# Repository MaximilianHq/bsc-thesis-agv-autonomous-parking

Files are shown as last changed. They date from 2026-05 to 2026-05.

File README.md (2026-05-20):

# BSc Thesis – AGV Autonomous Parking

Bachelor thesis project focused on developing an autonomous parking system prototype 
using an **Automated Guided Vehicle (AGV)** and a **Supervisory System (ÖS)**.

Developed in collaboration with **Autopark AB**.

<p align="center">
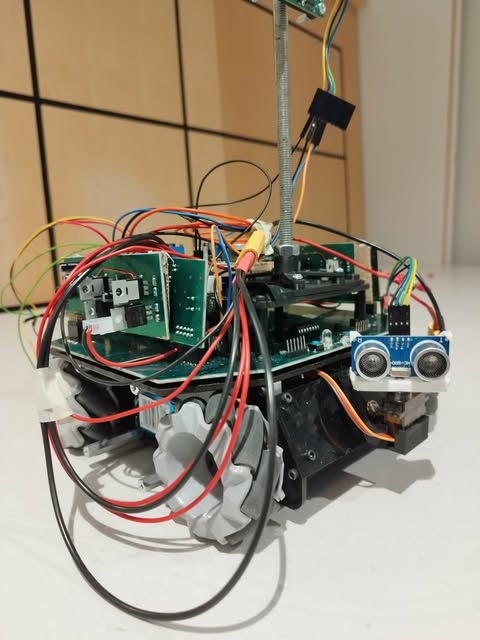
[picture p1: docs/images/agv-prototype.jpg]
  
</p>

<p align="center">
  <i>AGV prototype used for autonomous parking demonstrations</i>
</p>

---

## Overview

This project explores a cost-effective autonomous parking solution for **non-self-parking vehicles**.

The concept is based on an **AGV capable of towing vehicles** by lifting the front axle and transporting 
them to available parking spaces inside a parking garage. The system combines autonomous navigation
with a supervisory control system that handles route planning, parking allocation, and real-time monitoring.

The project demonstrates an integrated interaction between:

- **AGV (Automated Guided Vehicle)** — responsible for physical navigation and vehicle transportation
- **Supervisory System (ÖS)** — responsible for logistics, planning, and visualization

Communication between the AGV and the supervisory system is handled wirelessly via **Bluetooth**.

---

## Project Objective

The objective is to develop a fully functional prototype where the AGV:

1. Retrieves a vehicle from the parking entrance  
2. Selects the optimal parking location  
3. Navigates autonomously to the parking spot  
4. Parks the vehicle  
5. Returns to the entrance  

The complete cycle should be repeatable **at least five times within ten minutes**, 
coordinated through instructions from the supervisory system.

---

## System Architecture

### AGV Subsystem

The AGV is responsible for:

- Autonomous navigation
- Vehicle transport
- Obstacle avoidance
- Parking execution
- Wireless communication with the supervisory system

The AGV software is developed using **PlatformIO** and runs on an embedded microcontroller architecture.

<p align="center">
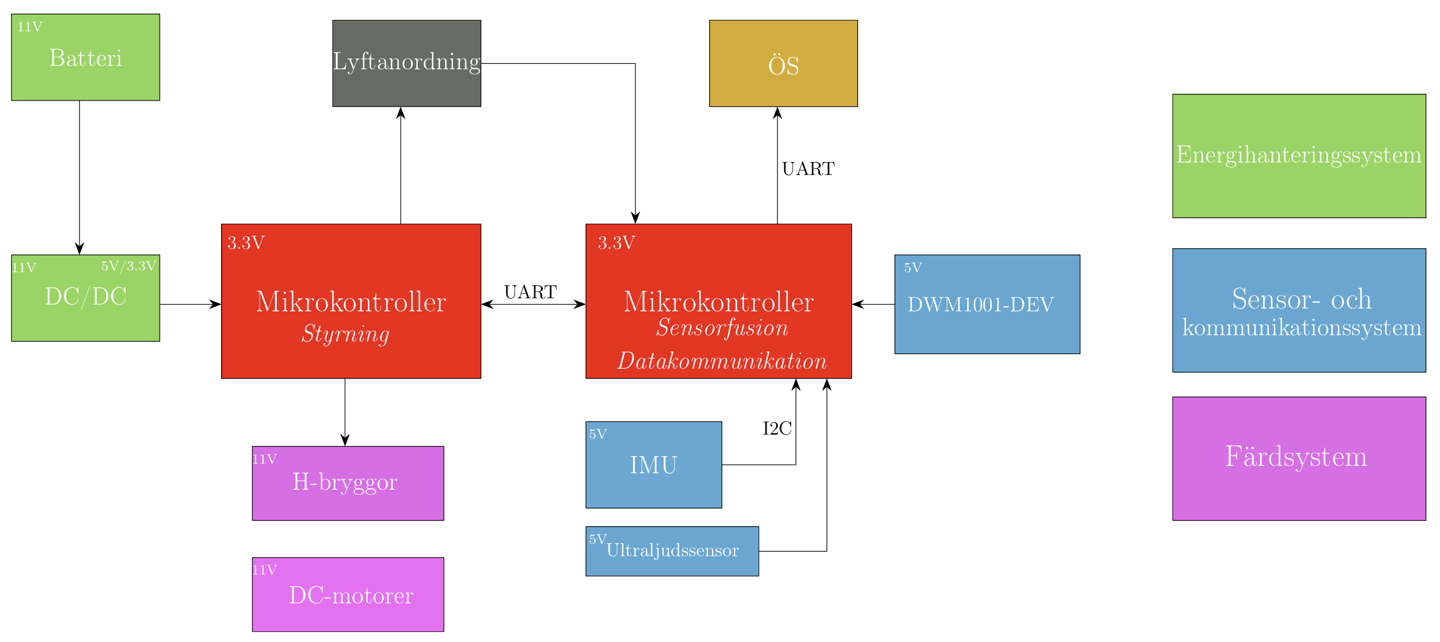
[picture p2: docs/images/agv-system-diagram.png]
  
</p>

### Supervisory System (ÖS)

The supervisory system is responsible for:

- Parking space selection
- Route optimization
- Real-time AGV tracking
- GUI visualization
- Task coordination

The supervisory system is developed in **Java**.

<p align="center">
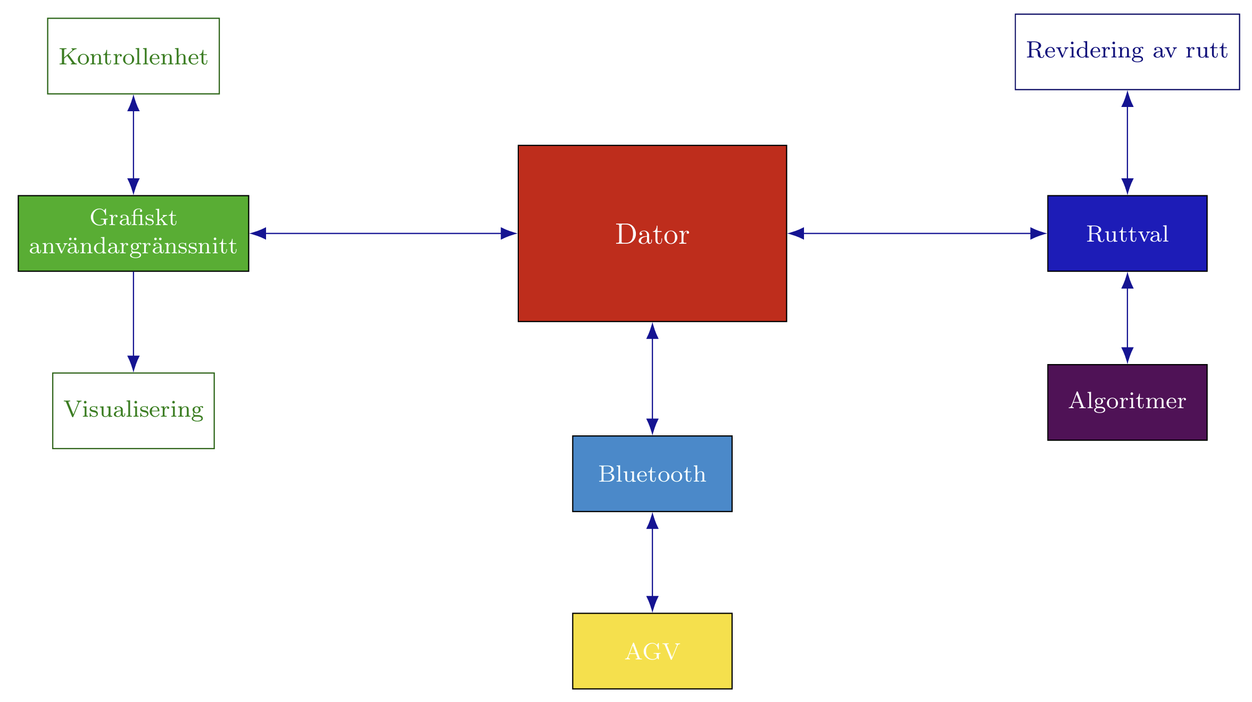
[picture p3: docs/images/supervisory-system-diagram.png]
  
</p>

---

## Repository Structure

```text
.
├── AGV/
│   ├── AGV CODE/          # PlatformIO embedded software
│   ├── DCDC/              # Power electronics
│   ├── Hbrygga/           # H-bridge hardware
│   └── Moderkort/         # Main control board
│
├── ÖS/
│   ├── Bluetooth/         # Wireless communication
│   └── GUI/               # Supervisory system interface
│
└── docs/
    └── images/
```

---

## Technologies

### AGV
- PlatformIO
- Embedded C/C++
- Bluetooth Communication
- Autonomous Navigation
- Sensor Fusion
- Kalman Filtering

### Supervisory System (ÖS)
- Java
- GUI Development
- Route Planning
- Real-Time Monitoring

---

## Authors

- André Olsson  
- Daniel Santana Wettermark  
- Esaias Ernfridsson  
- Fredrik Bergström  
- Hanna Boiardt  
- Maximilian Hallqvist  
- Maria Wallbom

---

## Project Type

Bachelor Thesis Project in Electrical Engineering [ED] / Kommunikation, transport och samhälle [KTS]

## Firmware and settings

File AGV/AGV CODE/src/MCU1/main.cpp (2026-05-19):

#include <Arduino.h>
#include <BluetoothSerial.h>
#include <ServoEasing.hpp>
#include <servo_continious.h>
#include <WiFi.h>
#include <types.h>
#include <ota.h>
#include <comm.h>
#include <sreg_handler.h>
#include <status_led.h>
#include <imu.h>
#include <dwm.h>
#include "lift.h"
#include "system_actions.h"
#include "sonar.h"

// ========== PINS ==========
// UART
#define PIN_MTM_TXD 16
#define PIN_MTM_RXD 17
#define PIN_DWM_TXD 32
#define PIN_DWM_RXD 33
// Sonar
#define PIN_SONAR_SERVO 18
#define PIN_SONAR_TRIG 19
#define PIN_SONAR_ECHO 35
// SHIFT REGISTER
#define PIN_SHREG_DATA 27
#define PIN_SHREG_LATCH 26
#define PIN_SHREG_CLK 25
// CRANE
#define PIN_CRANE_SERVO 23
#define PIN_CRANE_ENDSTOP 36
#define PIN_CRANE_BEGINSTOP 39
// IMU
#define PIN_SCL 22
#define PIN_SDA 21

// ========== DEFINITIONS ==========
#define UART_BAUD 115200
#define WATCHDOG 500 // ms

constexpr int SONAR_RANGE = 150; // mm
constexpr int SONAR_SPEED = 150; // mm
constexpr int SONAR_ANGLE = 75;  // ∓ deg

// ---------- COMM ----------
BluetoothSerial SerialBT;

Comm comm_bt(SerialBT, "BT");
Comm comm_mcu(Serial1, "MCU");

// ---------- LEDS ----------
SRegHandler sreg(PIN_SHREG_DATA, PIN_SHREG_CLK, PIN_SHREG_LATCH);
StatusLED led_sys(sreg, SRegHandler::pin_sreg::QA,
                  SRegHandler::pin_sreg::QB,
                  SRegHandler::pin_sreg::QC,
                  true);
StatusLED led_cmd(sreg, SRegHandler::pin_sreg::QD,
                  SRegHandler::pin_sreg::QE,
                  SRegHandler::pin_sreg::QF,
                  true);

Lift crane(PIN_CRANE_SERVO, PIN_CRANE_BEGINSTOP, PIN_CRANE_ENDSTOP, 1, false);

// ---------- POS ----------
DWM dwm(Serial2);
IMU imu(PIN_SDA, PIN_SCL);

SysCtrl sysctrl(comm_bt, comm_mcu, led_sys, led_cmd, dwm, crane);

// ---------- SONAR ----------
Sonar::SonarConfig sonar_cfg{
    PIN_SONAR_SERVO,
    PIN_SONAR_TRIG,
    PIN_SONAR_ECHO,
    SONAR_RANGE,
    SONAR_SPEED,
    SONAR_ANGLE,
    90,
    0,
    180,
    false};
Sonar sonar(sonar_cfg, sysctrl);

// ========== GLOBALS ==========
Debug g_debug;
unsigned long last_packet_time = 0;

// ========== PROTOTYPES ==========
void blt_status_routine();
void watchdog_routine();

void setup()
{
    // ========== STATE ==========
    sreg.setup();
    led_sys.setup();
    led_cmd.setup();
    led_cmd.set_status(StatusLED::State::STATUS_BOOT);

    // ========== UART ==========
    Serial.begin(UART_BAUD, SERIAL_8N1); // PC
    Serial1.begin(UART_BAUD, SERIAL_8N1,
                  PIN_MTM_TXD, PIN_MTM_RXD); // MCU2
    Serial2.begin(UART_BAUD, SERIAL_8N1,
                  PIN_DWM_TXD, PIN_DWM_RXD); // DWM
    Serial.setTimeout(30);                   // PC
    Serial1.setTimeout(30);                  // MCU2
    Serial2.setTimeout(30);                  // DWM

    Serial.println("[MAIN] Running setup...");

    // ========== NETWORK ==========
    SerialBT.begin("AGV_BT_G2"); // ÖS
    Serial.println("[BT] Bluethooth active");
    // ota_begin("QBit", "internet");

    // ========== SONAR ==========
    sonar.setup();

    // ========== CRANE ==========
    // crane.setup();

    // ========== POS ==========
    uint16_t cfg;
    if (dwm.dwm_cfg_get(cfg))
        Serial.println("[DWM] cfg_get ok");
    imu.setup();

    // ========== END ==========
    Serial.println("[MAIN] Setup finished");

    // ========== CALIBRATION ==========
    // if (!sysctrl.on_startup())
    //     Serial.println("[SYSCTRL] WARNING - Calibration Failed");

    // watchdog start
    last_packet_time = millis();
}

void loop()
{
    // ========== ROUTINES ==========
    // ota_handle();
    //  read BT. packet: ös movement, ös command
    //  $TCXXYYTTC\n or $TCCC\n

    blt_status_routine();
    // watchdog_routine();

    // ========== UPDATES ==========
    sonar.update();
    // crane.update();
    led_sys.update();
    led_cmd.update();
    sysctrl.update();

    // ========== CODE ==========

    // ---------- COMM ----------
    // Read from Bluetooth and process packet
    Comm::Packet bt_pkt;
    if (comm_bt.read(bt_pkt))
    {
        sysctrl.on_bt_pkt_recieved(bt_pkt);
        last_packet_time = millis();
    }

    // Read from MCU2 and process packet
    Comm::Packet mcu_pkt;
    if (comm_mcu.read(mcu_pkt))
        sysctrl.on_mcu_pkt_recieved(mcu_pkt);

    // ---------- DWM ----------
    DwmState d;
    ImuState i;
    if (dwm.read(d))
    {
        if (imu.read(i))
            sysctrl.on_new_position_data(d, i);
        else if (g_debug.imu)
            Serial.println("[IMU] no read");
    }
    else if (g_debug.dwm)
        Serial.println("[DWM] no read");
}

void blt_status_routine()
{
    if (SerialBT.hasClient())
        led_sys.set_status(StatusLED::State::STATUS_BLE_CONNECTED);
    else
        sysctrl.on_bt_no_connect();
}

void watchdog_routine()
{
    if (millis() - last_packet_time > WATCHDOG)
    {
        sysctrl.on_stop();
        if (g_debug.mcu1)
            Serial.println("[WATCHDOG] WARNING - Stopping AGV");
        last_packet_time = millis();
    }
}

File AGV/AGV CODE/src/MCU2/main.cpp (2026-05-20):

#include <Arduino.h>
#include <types.h>
#include <comm.h>
#include <ota.h>
#include <motor_driver.h>
#include "system_actions.h"

// UART
#define PIN_MTM_TXD 23
#define PIN_MTM_RXD 22
// DRIVER
#define PIN_ERR 34
#define PIN_EN 21
#define PIN_DRV 32
// DIR: v physical v
// [PWM4] [PWM3]
// [PWM1] [PWM2]
#define PIN_DIR1 25
#define PIN_DIR2 33
#define PIN_DIR3 26
#define PIN_DIR4 27
// PWM: v physical v
// [PWM4] [PWM3]
// [PWM1] [PWM2]
#define PIN_PWM1 18
#define PIN_PWM2 19
#define PIN_PWM3 17
#define PIN_PWM4 16

// ========== DEFINITIONS ==========
#define UART_BAUD 115200

MotorDriver::MotorDriverConfig cfg = {
    {PIN_DIR1, PIN_PWM1, 0, true},
    {PIN_DIR2, PIN_PWM2, 1, false},
    {PIN_DIR3, PIN_PWM3, 2, true},
    {PIN_DIR4, PIN_PWM4, 3, false},
    PIN_DRV,
    PIN_EN,
    PIN_ERR};

MotorDriver md(cfg);

Comm comm_mcu(Serial1, "MCU");
AGVCtrl sysctrl(comm_mcu, md);

// ========== GLOBALS ==========
Debug g_debug;

// ========== PROTOTYPES ==========

void setup()
{
    // ========== UART ==========
    Serial.begin(UART_BAUD, SERIAL_8N1); // PC
    Serial1.begin(UART_BAUD, SERIAL_8N1,
                  PIN_MTM_RXD, PIN_MTM_TXD); // MCU1
    Serial.setTimeout(30);                   // PC
    Serial1.setTimeout(30);                  // MCU1

    Serial.println("[MAIN] Running setup...");

    // ========== NETWORK ==========
    // ota_begin("QBit", "internet");

    // ========== MOTOR DRIVER ==========
    md.setup();
    // md.temperature_error_reset_all();
    md.outputs_enable();
    md.drivers_enable();

    // ========== END ==========
    Serial.println("[MAIN] Setup finished");
}

void loop()
{
    // ========== UPDATES ==========
    md.update();

    // ========== ROUTINES ==========

    // ========== CODE ==========

    // Read from MCU1 and process packet
    Comm::Packet mcu_pkt;
    if (comm_mcu.read(mcu_pkt))
    {
        Serial.println("HELP");
        sysctrl.on_mcu_pkt_recieved(mcu_pkt);
    }
    delay(20);
}

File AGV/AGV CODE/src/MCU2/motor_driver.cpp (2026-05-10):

#include <Arduino.h>
#include <types.h>
#include "motor_driver.h"

MotorChannel::MotorChannel(MotorChannelConfig &cfg)
    : _pin_dir(cfg.pin_dir), _pin_pwm(cfg.pin_pwm),
      _chnl(cfg.channel), _invert_dir(cfg.invert_dir) {}

void MotorChannel::execute_move(bool dir, uint8_t percent)
{
    digitalWrite(_pin_dir, (dir ^ _invert_dir) ? LOW : HIGH);
    ledcWrite(_chnl, percentage_to_bits(percent));
}

void MotorChannel::stop() { ledcWrite(_chnl, 0); }

uint32_t MotorChannel::percentage_to_bits(uint8_t percent)
{
    if (percent > 100)
        percent = 100;

    uint32_t max_duty = (1UL << PWM_RES) - 1;

    return (percent * max_duty + 50) / 100;
}

void MotorChannel::_setup()
{
    pinMode(_pin_dir, OUTPUT);
    ledcSetup(_chnl, PWM_FREQ, PWM_RES);
    ledcAttachPin(_pin_pwm, _chnl);
    stop();
}

MotorDriver::MotorDriver(MotorDriverConfig &cfg)
    : c1(cfg.c1), c2(cfg.c2), c3(cfg.c3), c4(cfg.c4),
      _pin_drv(cfg.pin_drv), _pin_en(cfg.pin_en), _pin_err(cfg.pin_err) {}

void MotorDriver::setup()
{
    if (g_debug.driver)
        Serial.println("[DRIVER] Running setup...");

    pinMode(_pin_drv, OUTPUT);
    pinMode(_pin_en, OUTPUT);
    pinMode(_pin_err, INPUT);

    outputs_disable();
    drivers_disable();

    c1._setup();
    c2._setup();
    c3._setup();
    c4._setup();

    if (g_debug.driver)
        Serial.println("[DRIVER] Setup finished");
}

void MotorDriver::update()
{
    if (g_debug.driver && has_error())
        Serial.println("[DRIVER] Error detected");

    if (_timed_move_active)
    {
        if (millis() - _move_start_time >= _move_duration)
        {
            channels_stop_all();
            _timed_move_active = false;
        }
    }
}

void MotorDriver::drivers_enable() { digitalWrite(_pin_en, HIGH); }
void MotorDriver::drivers_disable() { digitalWrite(_pin_en, LOW); }
void MotorDriver::drivers_restart()
{
    if (g_debug.driver)
        Serial.println("[DRIVER] Restarting drivers...");
    drivers_disable();
    delayMicroseconds(10);
    drivers_enable();
}

void MotorDriver::outputs_enable() { digitalWrite(_pin_drv, LOW); }
void MotorDriver::outputs_disable() { digitalWrite(_pin_drv, HIGH); }
void MotorDriver::outputs_restart()
{
    if (g_debug.driver)
        Serial.println("[DRIVER] Restarting outputs...");
    outputs_disable();
    delayMicroseconds(10);
    outputs_enable();
}

void MotorDriver::channels_stop_all()
{
    if (g_debug.driver)
        Serial.println("[DRIVER] Stopping all channels...");
    c1.stop();
    c2.stop();
    c3.stop();
    c4.stop();
}

bool MotorDriver::has_error()
{
    return (digitalRead(_pin_err) && // IF SPAM CHANGE TO HIGH
            digitalRead(_pin_en) &&
            digitalRead(_pin_drv))
               ? true
               : false;
}

void MotorDriver::temperature_error_reset_all()
{
    if (g_debug.driver)
        Serial.println("[DRIVER] Attempting temperature error reset...");

    // #1
    drivers_disable();
    outputs_disable();
    delayMicroseconds(10);
    // #2
    drivers_enable();

    uint8_t i = 0;
    uint8_t lim = 5;
    do
    {
        // #3
        delay(2);
        // #4
        outputs_enable();
        // #5
        delay(2);
        // #6
        outputs_disable();
        // #7
        delayMicroseconds(100);
    } while (!digitalRead(_pin_err) && i++ < lim);

    if (g_debug.driver && i >= lim)
        Serial.println("[DRIVER] Temerature error not fixable");
    else if (g_debug.driver)
        Serial.println("[DRIVER] Temerature error reset");
}

void MotorDriver::move(uint8_t cmd, uint8_t spd_percent, unsigned long duration_ms)
{
    if (duration_ms > 0)
    {
        channels_stop_all();
        _move_start_time = millis();
        _move_duration = duration_ms;
        if (g_debug.driver && _timed_move_active)
            Serial.println("[DRIVER] Exicuting new movement...");
        _timed_move_active = true;
    }
    else
    {
        _timed_move_active = false;
    }

    // CALIBRATION VARIABLES
    uint8_t spd_diff = spd_percent / 2; // For curved trajectories, slows down one of the sides
    double comp_move_right = 0;
    double comp_move_left = 0;

    switch (cmd)
    {
    case 0x00:
        // Forward
        c1.execute_move(true, spd_percent);
        c2.execute_move(true, spd_percent);
        c3.execute_move(true, spd_percent);
        c4.execute_move(true, spd_percent);

        if (g_debug.driver)
            Serial.println("[DRIVER] Exicuted new movement: Forward");
        break;

    case 0x01:
        // Backward
        c1.execute_move(false, spd_percent);
        c2.execute_move(false, spd_percent);
        c3.execute_move(false, spd_percent);
        c4.execute_move(false, spd_percent);

        if (g_debug.driver)
            Serial.println("[DRIVER] Exicuted new movement: Backward");
        break;

    case 0x02:
        // Right
        c1.execute_move(true, spd_percent);
        c2.execute_move(false, spd_percent);
        c3.execute_move(false, spd_percent);
        c4.execute_move(true, spd_percent);

        if (g_debug.driver)
            Serial.println("[DRIVER] Exicuted new movement: Right");
        break;
    case 0x03:
        // Left
        c1.execute_move(false, spd_percent);
        c2.execute_move(true, spd_percent);
        c3.execute_move(true, spd_percent);
        c4.execute_move(false, spd_percent);

        if (g_debug.driver)
            Serial.println("[DRIVER] Exicuted new movement: Left");
        break;
    case 0x04:
        // Forward-Right
        c1.execute_move(true, spd_percent);
        c2.stop();
        c3.stop();
        c4.execute_move(true, spd_percent);

        if (g_debug.driver)
            Serial.println("[DRIVER] Exicuted new movement: Forward-Right");
        break;
    case 0x05:
        // Forward-Left
        c1.stop();
        c2.execute_move(true, spd_percent);
        c3.execute_move(true, spd_percent);
        c4.stop();

        if (g_debug.driver)
            Serial.println("[DRIVER] Exicuted new movement: Forward-Left");
        break;
    case 0x06:
        // Backward-Right
        c1.stop();
        c2.execute_move(false, spd_percent);
        c3.execute_move(false, spd_percent);
        c4.stop();

        if (g_debug.driver)
            Serial.println("[DRIVER] Exicuted new movement: Backward-Right");
        break;

    case 0x07:
        // Backward-Left
        c1.execute_move(false, spd_percent);
        c2.stop();
        c3.stop();
        c4.execute_move(false, spd_percent);

        if (g_debug.driver)
            Serial.println("[DRIVER] Exicuted new movement: Backward-Left");
        break;

    case 0x08:
        // Turning-Right
        c1.execute_move(true, spd_percent);
        c2.execute_move(false, spd_percent);
        c3.execute_move(true, spd_percent);
        c4.execute_move(false, spd_percent);

        if (g_debug.driver)
            Serial.println("[DRIVER] Exicuted new movement: Turning-Right");
        break;
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

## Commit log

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2026-04-03 Rename UWB to DWM and improve debug logs
    Rename UWB module files (uwb.cpp/uwb.h -> dwm.cpp/dwm.h) and update includes accordingly. Replace uwb debug flag with dwm in types.h and add a driver debug flag. Standardize and prefix runtime prints (DWM, OTA, SONAR) for clearer logging, add an obstacle position debug log in sonar, and tidy minor sonar init messages. Changes are mostly renames and logging enhancements; functional behavior is unchanged.
    [dwm.cpp, sonar.cpp]
2026-04-03 Add MCU2 motor driver, types and sketch
    Add MCU2 firmware components: new Arduino sketch (MCU2.ino), motor driver implementation (motor_driver.cpp/h) and shared types (types.h). Implements MotorDriver and MotorChannel classes with PWM helpers, channel setup/stop, enable/disable control, temperature-error reset routine and timed move support. Provides global debug/state structs and wiring configuration in the sketch to initialize and exercise the driver.
    [motor_driver.cpp]
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2026-04-06 Sonar: add speed/angle, timeout and usage
    Refactor Sonar API and MCU1 usage to support configurable scan speed and angle, and to handle timeouts/absent echoes. Changes include:
    - Sonar constructor now accepts sonar_speed and sonar_angle and stores them (_sonar_speed, _sonar_angle, _sonar_range).
    - Updated sonar.h defaults (servo angle range 0..180) and removed global SERVO_SPEED constant.
    - MCU1.ino: replaced SONAR_RANGE constant types, added SONAR_SPEED and SONAR_ANGLE, updated Sonar instantiation and now react to sonar.update() returning true by setting LED status and retrieving obstacle position.
    - sonar.cpp: use pulseIn() with a computed timeout, return false when no echo, compute dista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
    [sonar.cpp]
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2026-04-11 Refactor comm/sonar and add SysCtrl actions
    Introduce a new IActions interface and SysCtrl (system_actions.{h,cpp}) to centralize system-level actions and route BT/MCU packets. Update MCU1.ino to use SysCtrl and a Sonar::SonarConfig when constructing Sonar. Rework Comm to parse sequence and CRC fields correctly, handle ACK ('A') packets, and wire PacketHandler to IActions; add sent/received packet buffers and ACK handling. Refactor Sonar to accept a config struct and IActions, invoking on_obstacle_detected on detection. Replace previous ad-hoc StaticVector with a templated StaticVector<T,N> (fixed bounds, pop/pop_front bugs, and new utilities: pop_if, find_if, clear). Update types (AgvMotion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
    [sonar.cpp, system_actions.cpp, system_actions.h]
2026-04-11 Refactor comm, servo, sonar and system actions
    Remove legacy agv_state files and apply multiple refactors and fixes across MCU1 code: improve const-correctness, encapsulation and packet handling.
    Key changes:
    - Deleted agv_state.cpp/h (state update implementation removed).
    - MCU1.ino: call sysctrl.on_bt_no_connect() when no BT client and removed agv_state include.
    - comm.cpp: include system_actions.h; PacketHandler now uses member _pkt_buffer_sent, captures pkt by reference, and dereferences find_if result when writing.
    - servo_easy: normalized function signatures and formatting; rad2deg/deg2rad signatures simplified.
    - servo_easy.h: updated static method signatures.
    - sonar.cpp: compose Se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
    [sonar.cpp, system_actions.cpp, system_actions.h]
2026-04-11 PlatformIO reorg and communication/type refactor
    Move sources into a PlatformIO-friendly layout (AGV/AGV CODE/...), add platformio.ini, .gitignore, VSCode recommendations and lib/include/test READMEs. Rename many files (.ino -> main.cpp) and relocate libraries under lib/* and src/*.
    Refactor Comm and related types for stronger typing and safer parsing: Packet fields changed to fixed-width types (seq -> uint16_t, data -> uint8_t[], data_len -> uint8_t), internal parser index renamed (_read_index) and PacketHandler::get_sequence() returns uint16_t. Update packet CRC/serialization usage accordingly.
    Use references and forward declarations where appropriate (StatusLED now holds SRegHandler&; h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
    [dwm.cpp, main.cpp, motor_driver.cpp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]
2026-04-11 Add 8MB partitions, platformio configs, and fixes
    Add a new 8MB OTA partition table (partitions_8mb_ota_big.csv) and enable it for env:mcu1. Update platformio.ini with flash/cpu frequencies and flash mode, and set build filtering for MCU1/MCU2. In source: add SUPPRESS_HPP_WARNING define in MCU1 main to silence warnings, and fix an explicit uint8_t cast in comm.cpp when building ACK packets to avoid type warnings during checksum calculation.
    [partitions_8mb_ota_big.csv]
2026-04-12 Refactor PacketHandler -> ProtocolHandler
    Rename PacketHandler to ProtocolHandler and switch sequence from uint16_t to uint8_t. Add sequence iteration and packet buffer tracking (add_buffer_sent/add_buffer_rcvd), change ack creation to a private _make_ack, and ensure crc is computed on write when missing. Update SysCtrl to use ProtocolHandler, move per-protocol packet handling into SysCtrl (_process_bt_packet/_process_mcu_packet), add forwarding logic to MCU with sequence/buffer updates, and introduce a Debug IAction flag. Misc: remove unused handler subclasses and a stale TODO in MCU1 main.
    [main.cpp]
2026-04-13 Refactor comm, system actions, LED, and drivers
    Multiple refactors and fixes across comms, system actions, LED states, static vector, and MCU drivers:
    - comm: improve debug tags, remove unused include, add protocol sequence overflow warning, and ensure received packets are buffered when approved.
    - ProtocolHandler: make methods non-virtual, warn on sequence overflow, and record approved packets to receive buffer.
    - status_led: reorder/adjust enum and LED color/config entries for clarity and correct mappings.
    - static_vector: add bounds-checked operator[], fix pop_if iteration to avoid skipping elements, and adjust pop/pop_back behavior with error checks.
    - platformio.ini: pin espressif32 pl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
    [main.cpp, motor_driver.cpp, sonar.cpp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]
2026-04-13 Replace IActions with SysCtrl and minor fixes
    Replace the abstract IActions interface with concrete SysCtrl across MCU1/MCU2 and core comm modules. Update ProtocolHandler to accept SysCtrl and store it, fix no-op buffer methods to push_back on sent/rcvd packet buffers, and adjust Sonar constructor and member types to use SysCtrl. Correct a memcpy offset in dwm_get_pos and fix a parameter name typo (period_moving_ms). Implement on_new_motion to push packets into the motion buffer and remove override/virtual declarations where appropriate. These changes unify action handling and fix several small bugs and typos.
    [dwm.cpp, sonar.cpp, system_actions.cpp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]
2026-04-13 Use static_cast and include seq in CRC
    Replace C-style casts with static_cast across Comm and LED code for stronger type-safety and clearer intent. Fix Comm::csum to include pkt.seq in checksum calculation. Update debug prints and _str.write calls to use static_cast, and adjust ProtocolHandler ACK construction accordingly. Also apply casting cleanup in StatusLED:: _write_sreg_color and Sonar::setup (servo easing cast), and remove a couple of stale TODO comments in MCU1 main.
    [main.cpp, sonar.cpp]
2026-04-13 Add inter-MCU/BT comm and watchdog
    MCU1: Add a 500 ms watchdog (WATCHDOG) and last_packet_time to stop the AGV when no BT packets arrive; implement watchdog_routine called from loop. Replace bt_test2 with robust packet handling: read Bluetooth and MCU2 packets via comm objects and forward to sysctrl, updating last_packet_time on BT receive. Minor comment normalization and setup reordering (start watchdog timer at end of setup).
    MCU2: Add comm and ota includes, instantiate Comm for MCU and SysCtrl tied to MotorDriver, initialize Serial1 and timeouts, and reorganize setup/loop to update motor driver continuously. Read packets from MCU1 in loop and forward to sysctrl. These changes enable inte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
    [main.cpp]
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2026-04-27 Update UART config, motor channels and driver logic
    Configure UART pins and mode for MCU1 (add PIN_MTM_TXD/PIN_MTM_RXD, use SERIAL_8N1 and Serial1.begin with explicit RX/TX). Extend MotorDriver channel config to include LEDC channel indices and switch MotorChannel to call ledcWrite with the channel instead of a PWM pin. Invert outputs_enable/outputs_disable polarity and correct has_error logic to use the proper pin read polarity. Increase initial move power/duration and add a startup delay. Temporarily comment out MCU packet reading for now.
    [main.cpp, motor_driver.cpp]
2026-05-04 Update LED, StaticVector, and MCU serial/pins
    Status LED: make STATUS_BLE_CONNECTED blink like BLE_SEARCHING.
    StaticVector: change push_back to discard oldest element when full, add pop_front_discard helper, adjust pop/pop_front behaviors and error message to handle empty container more safely.
    platformio.ini: disable custom partition line (commented out) for mcu1.
    MCU1: reorder sonar pin defines, add initial 5s startup delay, switch Serial.begin calls to explicit SERIAL_8N1 and use hardware UART pin parameters for Serial1/Serial2 while keeping timeouts.
    system_actions.cpp: minor whitespace cleanup.
    MCU2: swap MTM TX/RX pin definitions, comment out initial move/delay, enable reading pac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
    [main.cpp, system_actions.cpp]
2026-05-04 Refactor DWM, fix UART pins, add motor invert
    MCU1: Convert DWM code into a DWM class that owns a Stream reference and provides setup(), cfg/status/pos methods; add robust _read_exact(), _clear_rx(), and debug logging; move TVL success check into a private static. Instantiate and initialize DWM in main, poll status/position, and adjust update/loop ordering. Fix UART TX/RX pin assignments for Serial1 and Serial2. Minor reordering/added comments and includes.
    MCU2: Swap PWM pin defines to correct assignments, extend MotorChannelConfig with invert_dir and store it in MotorChannel; apply inversion when setting direction (XOR). Update MotorDriver config initializers and add simple demo moves in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
    [dwm.cpp, main.cpp, motor_driver.cpp]
2026-05-05 Fix motor pin mapping and init direction pins
    Update motor pin assignments to match real wiring (reorder DIR and PWM pin constants and add comments with physical mapping). Adjust MotorDriverConfig to flip direction flags for channels 0 and 2 (true -> false). Ensure direction GPIO is configured by calling pinMode(_pin_dir, OUTPUT) in MotorChannel::_setup(). These changes correct pin mapping and ensure direction pins are driven properly.
    [main.cpp, motor_driver.cpp]
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2026-05-06 Forward motion, add test_move, disable pos send
    Call _forward_to_mcu when a new motion packet arrives; add a test_move() helper to header that builds/sends a 'D' command packet to MCU and updates the protocol sequence/buffer; disable verbose position debug prints and comment out position update packet creation/sending in on_new_position_data to prevent sending position updates to the MCU (and reduce console noise).
    [system_actions.cpp, system_actions.h]
2026-05-06 Print heading in degrees instead of radians
    Convert upd.theta from radians to degrees when printing telemetry in SysCtrl::on_new_position_data for more readable heading output. Replaced Serial.print(upd.theta) with Serial.print(upd.theta * 180.0f / PI) in AGV/AGV CODE/src/MCU1/system_actions.cpp.
    [system_actions.cpp]
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2026-05-07 Add startup calibration and coordinate transforms
    Add coords.h with agv2dwm and dwm2agv helpers for converting between AGV and DWM/world coordinates. Implement a startup calibration flow: main.cpp calls SysCtrl::on_startup(dwm) and prints a warning if calibration fails; system_actions.cpp now includes dwm.h and implements SysCtrl::on_startup which reads two DWM measurements, commands MCU2 to drive forward, reads a second measurement, computes the AGV heading (theta) from the DWM delta, and pushes the initial AgvState. Expose on_startup in system_actions.h (forward-declare DWM). Also set initial theta to 0 in new-position handling and add a park.h include to MCU2/motor_driver.h.
    [main.cpp, system_actions.cpp, system_actions.h]
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2026-05-08 Retry DWM startup, add parking maneuvers
    Improve startup calibration reliability and add parking routines.\n\n- MCU1 main: add startup delay and log before calling SysCtrl::on_startup.\n- MCU1 system_actions: replace/rework SysCtrl::on_startup to retry DWM reads (with timeouts), forward a drive command to MCU2, perform a stop, re-read position, compute and store AGV theta, and add debug prints.\n- MCU2 motor_driver: add two new movement commands (0xF0, 0xF1) implementing multi-step parking maneuvers (sequences of wheel commands, delays and stops); minor whitespace fixes.\n- MCU2 motor_driver.h: comment out unused park.h include.\n\nThese changes aim to make initial calibration more robust an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
    [main.cpp, motor_driver.cpp, system_actions.cpp]
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2026-05-11 Rename coord funcs; improve startup/comm
    Refactor coordinates API and harden startup/communication logic.
    - lib/AGVCore/src/coords.h: renamed agv2dwm -> rel2agv and dwm2agv -> abs2agv, moved includes order, and made the DWM->AGV conversion accept an offset parameter (replacing the hardcoded 50 mm). Also cleaned up formatting/comments.
    - src/MCU1/system_actions.cpp: removed duplicated/older implementations and replaced with a consolidated, more robust set of routines. on_startup now retries DWM reads, logs progress, checks _forward_to_mcu failures and aborts on send errors, and uses consistent delays; forwarding, packet processing and _next_movement logic were consolidated and retained with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
    [system_actions.cpp]
2026-05-11 Rename iterate_sequence, add position packet send
    Rename ProtocolHandler::itterate_sequence() to iterate_sequence() and update all declarations and call sites. Replace debug flag g_debug.IAction with g_debug.sysctrl and update related logging checks. Add assembly and transmission of an AGV position packet (with serialized x, y, theta and CRC) in SysCtrl::on_new_position_data, updating protocol sequence and send buffer on success. Also include small formatting fixes (brace style in test_move, whitespace in types.h).
    [system_actions.cpp, system_actions.h]
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2026-05-11 Refactor positioning, IMU units & DWM offset
    Move DWM/IMU/motor driver sources into lib/AGVCore and update includes. Fix coordinate transforms to REP103 body frame (x forward, y left) and use cosf/sinf; add an abs2agv(Position, ang, offset) helper. Standardize IMU units to mm/s^2 and radians (and dt in seconds), introduce constants for deadzones and max valid dt, and guard against integrating across long sampling gaps. Update types to reflect unit changes. SysCtrl now accepts a DWM offset, applies it when converting tag positions to the AGV center, improves prediction/correction logic (velocity integration, reduced DWM gain, heading-alignment checks and thresholds), corrects startup calibrat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
    [main.cpp, system_actions.cpp, system_actions.h]
2026-05-11 Improve heading adjustment; remove sonar debug
    Refine heading-correction logic to avoid spurious updates for small/slow motions and ensure alignment to cardinal body axes. Introduced meaningful_motion check, stored last body-move angle (_last_body_move_ang), and snap/normalize helpers (_snap_body_motion_axis, _norm_ang). Heading error is now computed relative to the snapped body-motion axis before blending with IMU (uses _err_co_imu). Removed noisy Serial prints from sonar.update() and commented-out sysctrl.test_move() in setup. Also tweaked test_move packet payload (0x01 -> 0x03). These changes improve stability of heading adjustments and remove debug noise.
    [main.cpp, sonar.cpp, system_actions.cpp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]
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2026-05-12 Integrate crane servo (ServoContinious)
    Add support for a crane continuous servo and integrate ServoContinious into MCU1 control flow. Expose a new g_debug.crane flag, wire crane.setup() and crane.update() in main, and pass a ServoContinious instance into SysCtrl. Change the ServoContinious API (simplified constructor, default pulse values, renamed internal constants), add debug prints, apply invert handling in drive_manual, and fix duty calculation variable names. SysCtrl now stores a reference to the crane and handles new packet types to drive the crane (lift/lower), plus related header/include updates.
    [main.cpp, system_actions.cpp, system_actions.h]
2026-05-13 Enhance comm debug and positioning logs
    Improve communication debugging and packet parsing, tighten IMU logging, and add gating for positioning debug.
    - comm.cpp: Add print_hex_byte and debug_print_packet helpers; replace verbose ad-hoc prints with hex-formatted dumps; improve Comm::read to resync on '$', ignore CR/LF, handle restarts, and return packets immediately when complete; use debug_print_packet in write.
    - imu.cpp: Clarify calibration logs and minor formatting/comment tweaks.
    - types.h: Add Debug::positioning flag (default false) and fix struct termination.
    - main.cpp: Only print missing DWM/IMU messages when their debug flags are enabled and increase loop delay from 20ms to 200ms.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
    [main.cpp, system_actions.cpp]
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2026-05-13 Introduce Lift class and wire lift controls
    Replace the old library lift implementation with a new MCU-specific Lift class and integrate lift control into the system. Changes include:
    - Delete lib AGVCore/src/lift.h (removed duplicated/old lift implementation).
    - Tweak servo_continious default stop pulse from 1500 to 1520 us.
    - Add new AGV/AGV CODE/src/MCU1/lift.h: Lift wraps ServoContinious, handles begin/end endstops, and exposes lift/lower methods.
    - Update main.cpp to include lift.h, define begin/endstop pins, and instantiate Lift instead of ServoContinious for the crane.
    - Update system_actions.* to accept Lift&, add on_lift(bool) handler, handle 'L' BT packets to trigger lift/lower, a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
    [main.cpp, system_actions.cpp, system_actions.h]
2026-05-15 Decouple Lift from SysCtrl; add attach_sysctrl
    Remove SysCtrl& parameter from Lift constructor and make internal SysCtrl reference a nullable pointer (_sysctrl = nullptr). Add attach_sysctrl(SysCtrl&) to set the pointer after construction. Update main.cpp to construct the Lift (crane) without requiring SysCtrl at construction time. This resolves initialization/circular-dependency issues by allowing SysCtrl to be attached to Lift after both objects exist.
    [main.cpp]
2026-05-15 Disable comm debug; add motion value to log
    Turn off the comm debug flag in Debug (types.h) to reduce communication log noise. Update SysCtrl Bluetooth packet handling (system_actions.cpp) to print a concise prefix and the movement value (pkt.data[0]) instead of the previous lone println, giving clearer runtime information when new motion packets arrive.
    [system_actions.cpp]
2026-05-15 Add lift-done callback and timed lift control
    Notify SysCtrl when the lift reaches endstops and add optional duration control for lift movements. Changes: include system_actions.h in lift.h; call SysCtrl::on_lift_done() when endstop is hit; add optional duration parameter to lift() and lower() and forward to servo drive calls. Attach sysctrl to crane in main.cpp. Add SysCtrl::on_lift_done() implementation and declaration (sends a Comm::Packet, issues a timed lift command, and logs), and update related log messages.
    [main.cpp, system_actions.cpp, system_actions.h]
2026-05-15 Refactor Comm protocol and update motor/sysctrl
    Introduce fixed frame/data sizes and simplify Comm handling: add DATA_BYTES/FRAME_BYTES, compute CRC over DATA_BYTES, replace ad-hoc debug printer with pds-based dumps, harden read/write state machine (fixed indexing, resync, approved flag), and add clear_send_queue. Adjust ProtocolHandler send/queue behavior and ensure CRC is always computed when sending.
    Update types::pds signature/formatting and clean up debug output formatting. Change motor command opcodes to 0xD0..0xDD for movement cases. Remove an extra delay in main loop.
    SysCtrl changes: sanitize incoming motion packets (copy only 2 data bytes), clear motion buffer and proto send queu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
    [main.cpp, system_actions.cpp, system_actions.h]
2026-05-15 Refactor servo API and add crane homing
    Rename servo pulse fields to use _*_us and update calculations/prints (servo_continious.*). Change default stop_us to 1500 and update debug tag from [CRANE] to [Servo]. Add lift homing routine and run it during setup, change endstop pins to INPUT (was INPUT_PULLUP) and invert endstop logic to treat HIGH as triggered; add debug messages when stops are hit and call SysCtrl::on_lift(true) at startup (lift.h, main.cpp). Remove duration usage from lower() and ensure SysCtrl attaches to the crane in its constructor (system_actions.cpp). Small fixes to constrain/map usage to the new *_us names.
    [main.cpp, system_actions.cpp]
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2026-05-18 Refactor protocol & integrate DWM into SysCtrl
    Add non-blocking ProtocolHandler::update(), track last-sent packet and enforce forced re-send interval; simplify send/ack flow and add packet "is_critical" flag. Change Comm::Packet defaults (data_len, seq init) and remove explicit ACK CRC calc. Integrate DWM into SysCtrl (constructor, member _dwm) and move position offset handling into _to_agv_center; update startup/calibration loops to poll DWM and protocol handlers and send a calibration-complete packet. Update main to instantiate DWM/IMU earlier, call sysctrl.update(), and comment out crane init/update. Small fixes: lower homing speed in lift.h, toggle debug flags in types.h (enable comm, di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
    [main.cpp, system_actions.cpp, system_actions.h]
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2026-05-18 Refine LED states, servo timing, and crane flow
    Updates StatusLED enum and configurations (adds STATUS_MOVING and STATUS_LIFTING, adjusts colors/durations, and adds get_status()). Reworks ServoContinious to remove default duration parameters and use a 32-bit max sentinel (4294967295UL) for infinite duration. Modifies lift and homing to call servo.drive_forward and removes default args from lift/lower signatures. main: set boot LED on startup and re-enable Bluetooth status routine. system_actions: set appropriate LEDs (BOOT, MOVING, LIFTING), replace blocking crane wait with a non-blocking flag-based flow (_crane_lifting/_crane_done) and handle completion in the periodic update; also tweaks e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
    [main.cpp, system_actions.cpp, system_actions.h]
2026-05-18 Disable crane; tweak LED and sensor coeffs
    Temporarily disable crane operation by commenting out crane.setup() and crane.update() in main.cpp. Route movement-status indication to the command LED (_led_cmd) instead of the system LED in system_actions.cpp. Adjust sensor error coefficients in system_actions.h: increase _err_co_dwm from 0.20 to 0.75 and decrease _err_co_imu from 0.5 to 0.1 to change weighting/tolerance for DWM vs IMU processing (likely part of sensor tuning).
    [main.cpp, system_actions.cpp, system_actions.h]
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2026-05-19 Wrap theta to 0..2pi before scaling
    Add _wrap_ang_0_2pi helper and use it when computing theta in on_new_position_data. Theta is now normalized to the 0..2π range before being multiplied by 100 and stored as an int16, preventing negative angle encodings and ensuring a consistent representation across the system.
    [system_actions.cpp, system_actions.h]
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
